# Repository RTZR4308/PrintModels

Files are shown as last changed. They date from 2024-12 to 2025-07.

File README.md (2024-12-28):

# База 3D моделей РТЗР

### Структура репозиторію
`Виробник/Пристрій/Модель/виробник_пристрій_назва_моделі.stl`  
  
_Наприклад:_  
`DJI/RM510B/Ntype/dji_rm510b_4Ntype_mount_hdmi.stl`  
> Виробник та пристрій дублюються в назві файлу, щоб при його використанні поза межами репозиторію було простіше орієнтуватись в його призначенні. 

Кожна модель або категорія моделей має свій README з описом файлів, параметрами друку та виглядом моделі.

## Правила використання репозиторію
1. Притримуйтесь структури репозиторію.
2. Створюйте теги при додаванні нових версій моделей.
3. Застарівші моделі не видаляються, а переносяться в папку deprecated там же, де й були.
4. Додавайте файли формату `.stl` або `.3mf` + `.stl`.
5. Оновлюйте README при внесенні змін.

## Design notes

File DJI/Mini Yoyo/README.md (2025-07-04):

# Документація по MINI YOYO
> Дисклеймер!
> 
> Оригінальна ідея та реалізація Йойо належить "Майстерні Незламності" 24 ОМБр. Нашим завданням було реалізувати цю ідею для DJI Matrice 4T. В ході розробки виявили, що отриманий результат можна використати не тільки для DJI Matrice 4T, а й адаптувати для 3 серії DJI Mavic.
> 
> Всі матеріали, конструкція та ідея ***цієї версії*** Йойо належать "Майстерні Потужності" (робоча назва) ББС 12 бригади спеціального призначення НГУ "Азов".
>
> Автори: Кроп, Азот, Годзі.

## Елементи
1. Arduino Pro Mini 5V
2. Micro-Servo GH-S037 або аналог ідентичного розміру TK-S037
3. Фоторезистор
4. Резистор 10К
5. USB Type-C OTG 
6. USBASP програматор AVR (https://www.rcscomponents.kiev.ua/product/usbasp-prohramator-avr-v2-0-draiver-i-pz-na-saiti-rcscomponents-kiev-ua_46535.html)

## Прошивка
#### ПЕРЕД БУДЬ-ЯКИМИ МАНІПУЛЯЦІЯМИ З ПЛАТОЮ, ЇЇ ТРЕБА ПРОШИТИ.
> Код прошивки можна знайти в репозиторії.

### Як прошивати?
Arduino Pro Mini with Atmega328P 
https://www.instructables.com/Uploading-Sketch-to-Arduino-Pro-Mini-using-usbASP/

Arduino Pro Mini with Atmega328PB
https://www.youtube.com/watch?v=LvKr8gG_WNg

## Cхема пайки


## Реалізація кнопки відкривання/закривання важеля
Використовується оригінальна кнопки RESET на Arduino Pro Mini. Нам необхідно перерізати доріжки на платі, що відповідають за оригінальну функціональність кнопки. На фото позначено червоними стрілками.


### Результат
Перевірити Мультиметром на продзвонці.
Контакт, що ближчий до 7-8 контактів (нижній на фото) не дзвониться на GND.
Контакт, що ближчий до 11-12 контактів (верхній на фото) не дзвониться на RST.
signal-2025-07-03-205428_005
signal-2025-07-03-205428_004

Таким чином ми від'єднали кнопку від її оригінальної функції. Вона більше не діє як RESET.
Далі нам треба буде припаяти провід Від верхнього контакту (ближчий до 11-12 контактів) до A0, на який в нас припаяно фоторезистор та резистор. 

Також припаяти провід від нижнього контакту (ближчий до 7-8 контактів) до `VCC`. Ми можемо припаяти проводок напряму до VCC з іншої сторони плати. Або ж використати коротший шлях, припаявшись до дальньої сторони резистора біля контакта 6 (див. фото). Цей контакт іде напряму на VCC.


### Що ми цим зробили?
При натисканні кнопки, на контакт A0 будемо подано 5 вольт з VCC, що аналогічно сигналу з фоторезистора, коли на нього світить яскраве світло. По суті, ми імітуємо світіння ліхтариком на фоторезистор, тим самим відкриваючи важіль, що тримає саму йойошку.

## Фінальний вигляд плати
signal-2025-07-03-205428_006

### РОЗТАШУВАННЯ ФОТОРЕЗИСТОРА ЗАЛЕЖИТЬ ВІД МОДЕЛІ ДРОНА, НА ЯКИЙ ВСТАНОВЛЮЄТЬСЯ ЙОЙО. ДИВІТЬСЯ ВІДПОВІДНЕ КРІПЛЕНННЯ.
signal-2025-07-03-205428_007

# Покроковий процес збірки
signal-2025-07-03-205428_010
signal-2025-07-03-205428_011
signal-2025-07-03-205428_012
signal-2025-07-03-205428_013
signal-2025-07-03-205428_014
signal-2025-07-03-205428_015
signal-2025-07-03-205428_016
signal-2025-07-03-205428_017
signal-2025-07-03-205428_018
signal-2025-07-03-205428_019
signal-2025-07-03-205428_020
signal-2025-07-03-205428_022
signal-2025-07-03-205428_023
signal-2025-07-03-205428_024
signal-2025-07-03-205428_025
signal-2025-07-03-205428_026
signal-2025-07-03-205428_027
## ПЕРЕД ВСТАНОВЛЕННЯМ ВАЖЕЛЯ, НЕОБХІДНО ПІД'ЄДНАТИ ЙОЙО ДО ЖИВЛЕННЯ, АБИ СЕРВОПРИВІД ВСТАВ У ПОЧАТКОВЕ НУЛЬОВЕ ПОЛОЖЕННЯ.
signal-2025-07-03-205428_028
signal-2025-07-03-205428_029
## Гвинтик для важеля входить в комплект сервоприводу.
signal-2025-07-03-205428_030
signal-2025-07-03-205428_031
signal-2025-07-03-205428_032
signal-2025-07-03-205443
signal-2025-07-03-205443_002
signal-2025-07-03-205443_003
signal-2025-07-03-205443_004

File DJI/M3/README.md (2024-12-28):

# Моделі для DJI Mavic 3
### [IR Cover](IR%20Cover)  
  
Знімок екрана 2024-12-28 194825

### [Кріплення для спарки батарей](Dual%20Bat)  
  


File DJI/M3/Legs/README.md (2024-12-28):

# Деталі для ніг DJI Mavic 3
### :books: Опис файлів
- `dji_m3_back_leg_plate.stl` - прокладка для задньої ноги
- `dji_m3_leg_bl.stl` - подовження для задньої лівої ноги
- `dji_m3_leg_br.stl` - подовження для задньої правої ноги
- `dji_m3_leg_fl.stl` - подовження для передня лівої ноги
- `dji_m3_leg_fr.stl` - подовження для передня правої ноги

### :gear: Параметри друку
- **PETG**
- Заповнення **100%**

### :eyes: Вигляд та спосіб кріплення
#### Подовження для передньої лівої ноги


#### Подовження для задньої ноги


#### Прокладка для задньої ноги


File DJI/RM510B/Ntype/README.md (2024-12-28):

# Кріплення під Ntype перехідники для зовнішніх антен на контролер DJI RM510B
### :books: Опис файлів
- `dji_rm510b_2Ntype_mount.stl` - верхнє кріплення під 2 N-type перехідника
- `dji_rm510b_2Ntype_mount_hdmi.stl` - верхнє кріплення під 2 N-type перехідника з отвором під блок переноса HDMI та Type-C роз'ємів 
- `dji_rm510b_2Ntype_mount_hdmi_kit_a1m.3mf` - комплект для переробки пульта під 2 N-type з блоком HDMI та Type-C. Пресет для Bambu Lab A1 Mini
- `dji_rm510b_4Ntype_mount.STL` - верхнє кріплення під 4 N-type перехідника
- `dji_rm510b_4Ntype_mount_hdmi.STL` - верхнє кріплення під 4 N-type перехідника з отвором під блок переноса HDMI та Type-C роз'ємів 
- `dji_rm510b_bottom_holder.STL` - нижнє кріплення, що закриває оригінальні HDMI та Type-C роз'єми
- `dji_rm510b_cable_tunnel.STL` - тунель для кабелів-перехідників  HDMI та Type-C
- `dji_rm510b_hdmi_holder.STL` - блок переноса HDMI та Type-C роз'ємів
- `dji_rm510b_hdmi_holder_cover.STL` - кришка блок переноса HDMI та Type-C роз'ємів 
- `dji_rm510b_hdmi_holder_plug.STL` - заглушка для отвору під блок з роз'ємами

### :gear: Параметри друку
- **PETG**
- Заповнення **50%**

### :eyes: Вигляд та спосіб кріплення
#### Комплект під 2 N-type з переносом HDMI і Type-C роз'ємів наверх  

  
#### Варіант з переносом HDMI і Type-C роз'ємів наверх  

  
#### Варіант без HDMI і Type-C роз'ємів  


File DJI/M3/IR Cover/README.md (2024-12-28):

# Кришка для інфрачервоного датчика DJI Mavic 3
### :books: Опис файлів
- `dji_m3_IR_cover.stl` - оригінальна модель

### :gear: Параметри друку
- **PETG**
- Заповнення **85%**

### :eyes: Вигляд та спосіб кріплення
Знімок екрана 2024-12-28 194825

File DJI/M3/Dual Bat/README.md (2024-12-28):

# Кріплення для спарки батарей на DJI Mavic 3
### :books: Опис файлів
- `dji_m3_dual_bat.stl` - оригінальна модель
- `dji_m3_dual_bat_99scale_8parts_x1c.3mf` - пресет на 8 деталей для Bambu Lab X1 Carbon. **Модель зменшена до 99%.**
### :gear: Параметри друку
- PETG
- Заповнення 15-30%
- Масштаб 99% (в залежності від пластику та принтера)

### :eyes: Вигляд та спосіб кріплення
  
  
⚠️ **Виступи на внутрішній стороні деталі мають зайти в вентиляційні отвори на задній частині дрона**  


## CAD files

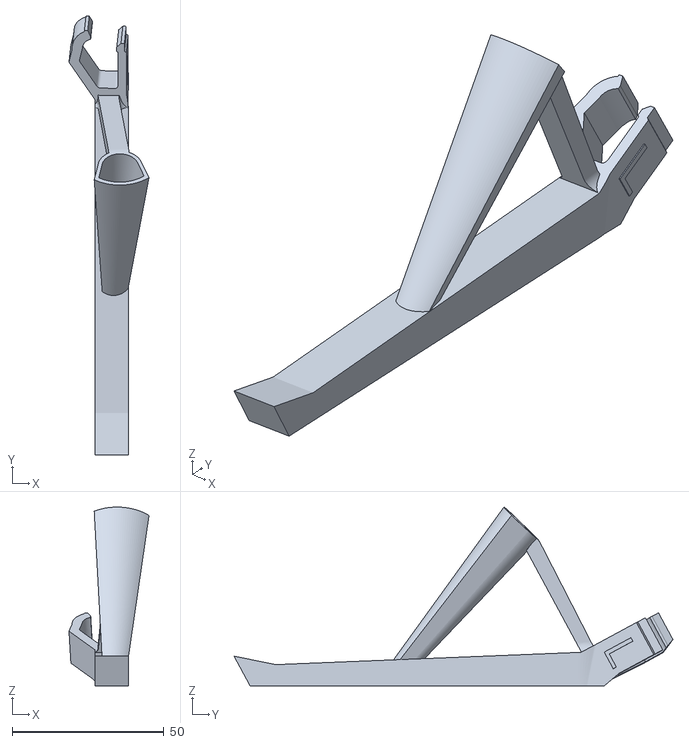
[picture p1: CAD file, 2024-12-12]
Autel/autel_4tmax_leg_lb.stl
26.4 x 144.6 x 58.9

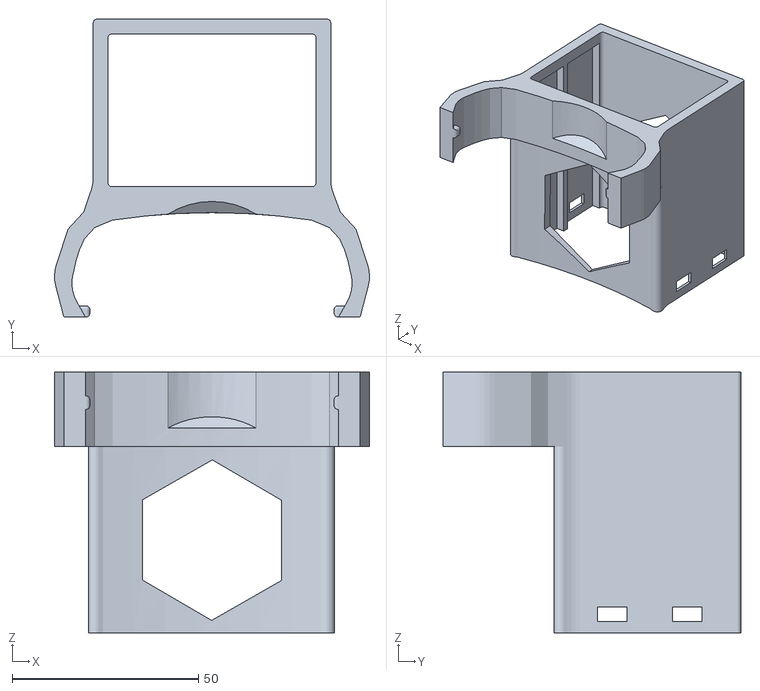
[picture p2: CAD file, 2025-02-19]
Autel/Dual Bat/autel_top_holder_V2.STL
84.6 x 80.0 x 70.0

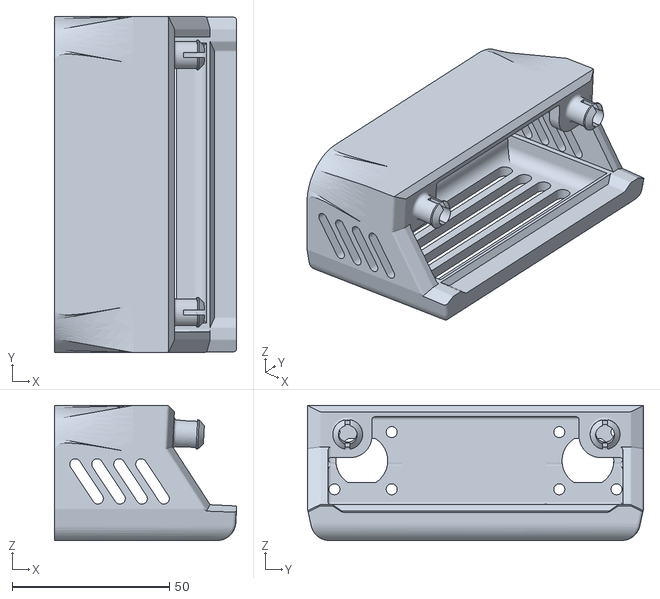
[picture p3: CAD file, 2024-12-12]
Controllers/2Ntype_4nut_Mount_air_.STL
58.1 x 107.0 x 43.0

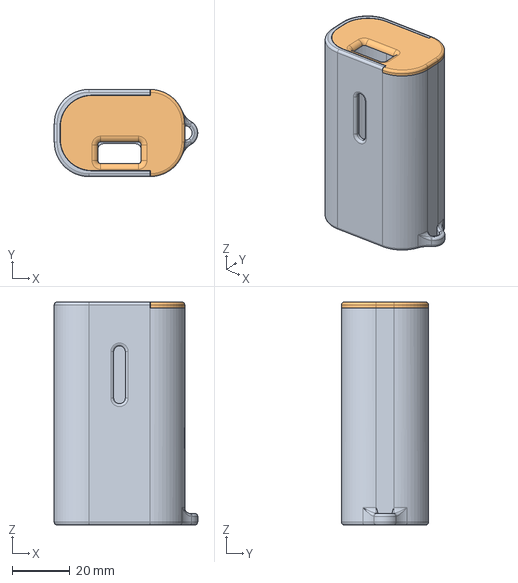
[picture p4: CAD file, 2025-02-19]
DJI/FPV/dji_fpv_googles_battery_case.step
49.7 x 30.2 x 77.2 mm

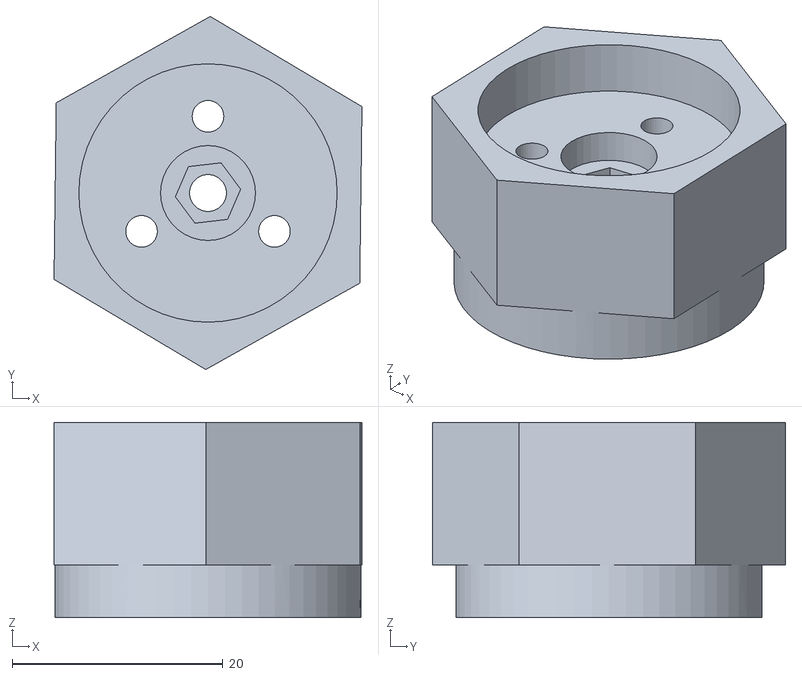
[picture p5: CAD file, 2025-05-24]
DJI/M3/dji_m3_motor_disasembler.STL
29.2 x 33.5 x 18.5

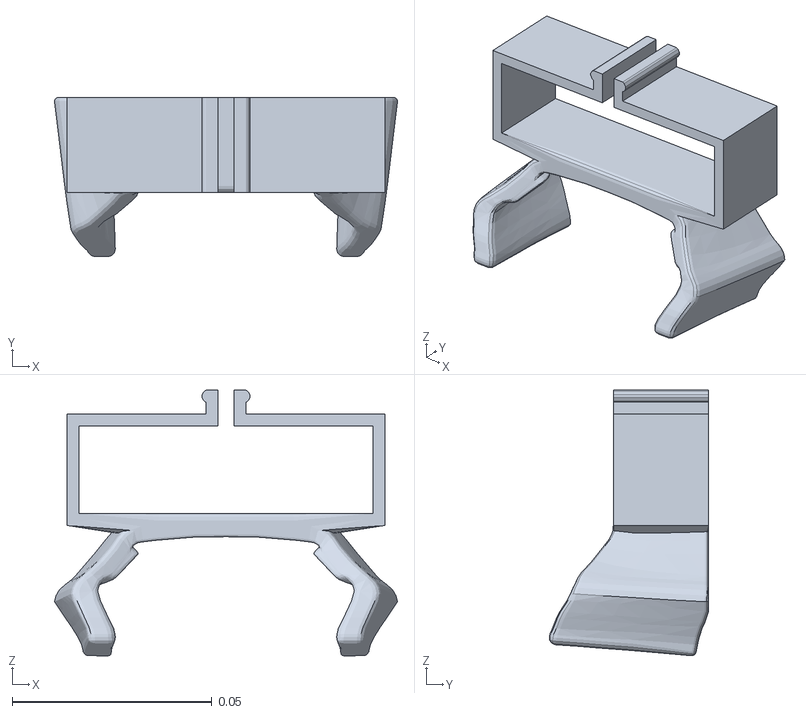
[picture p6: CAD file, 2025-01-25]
DJI/M3/Dual Bat/dji_m3_dual_bat_fpv.stl
0.0858 x 0.0398 x 0.0664

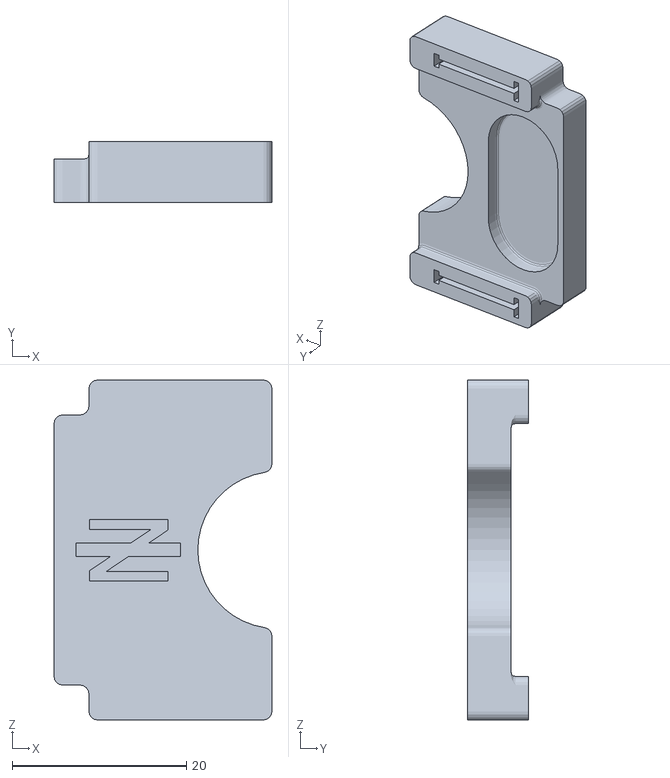
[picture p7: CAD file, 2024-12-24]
DJI/M3/IR Cover/dji_m3_IR_cover.stl
25.0 x 7.00 x 39.0

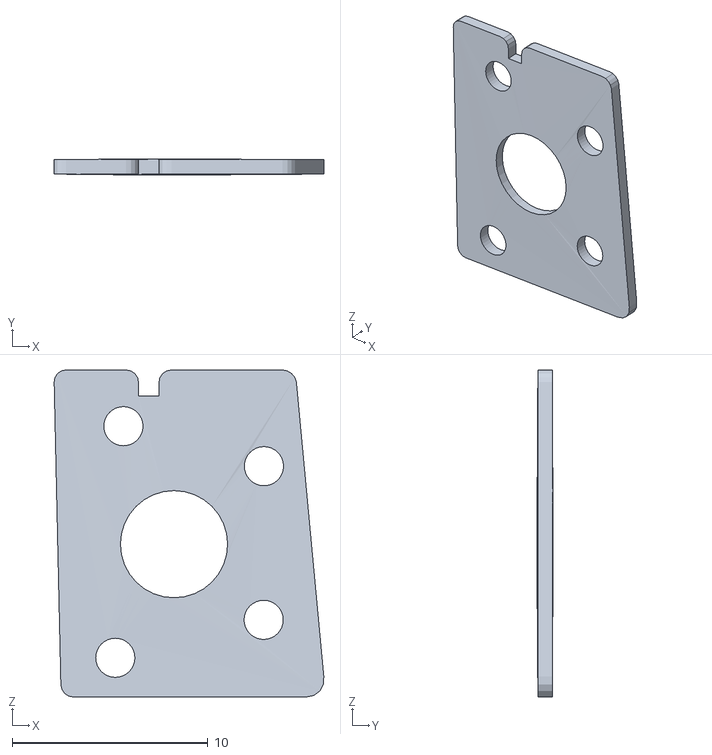
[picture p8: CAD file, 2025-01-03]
DJI/M3/Legs/dji_m3_back_leg_plate.stl
13.8 x 0.8 x 16.7

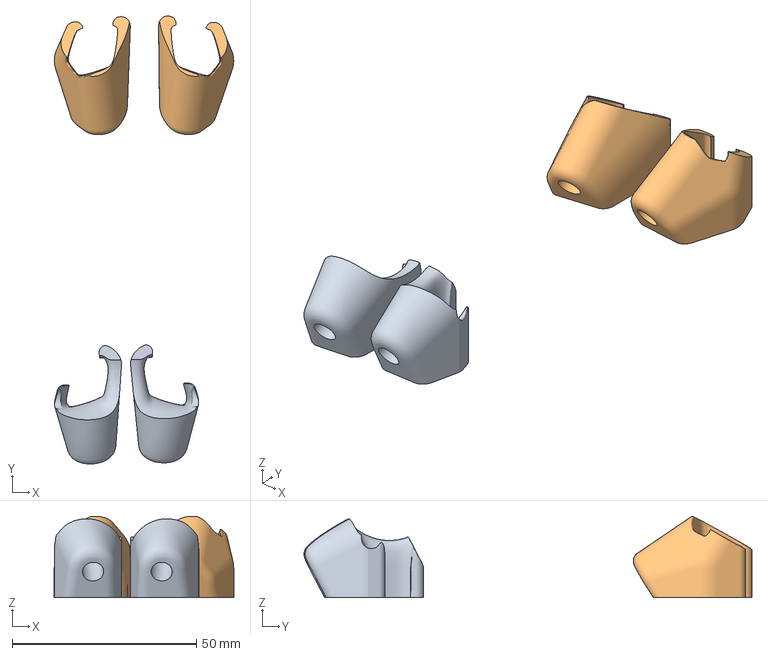
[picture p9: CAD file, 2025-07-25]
DJI/M4/dji_m4_arm_bracket_set.3mf
48.7 x 121.6 x 22.1 mm
Збірка x 2

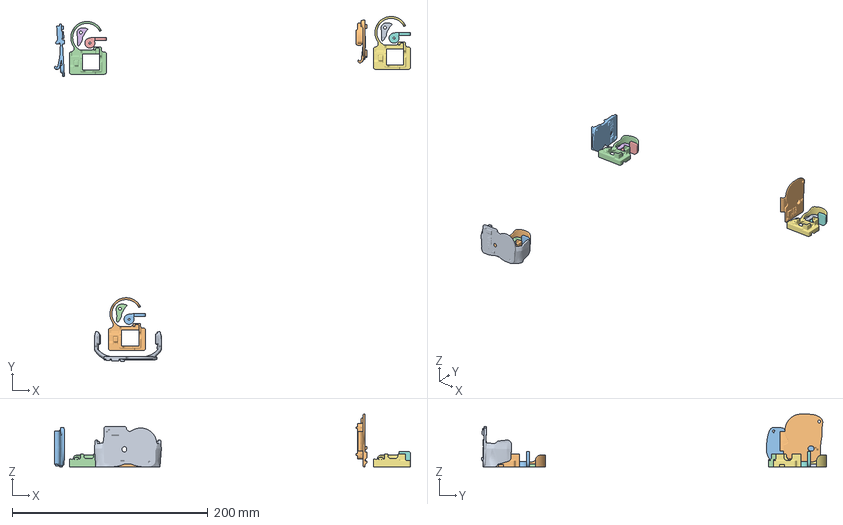
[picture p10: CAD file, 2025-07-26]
DJI/Mini Yoyo/dji_mini_yoyo_set.3mf
364.5 x 352.8 x 54.0 mm
dji_m4t_mini_yoyo_mount.stl
dji_m3_pro_mini_yoyo_mount.stl
dji_m3_mini_yoyo_mount.stl
mini_yoyo.stl_1 x 3
mini_yoyo.stl_2 x 3
mini_yoyo.stl_3 x 3

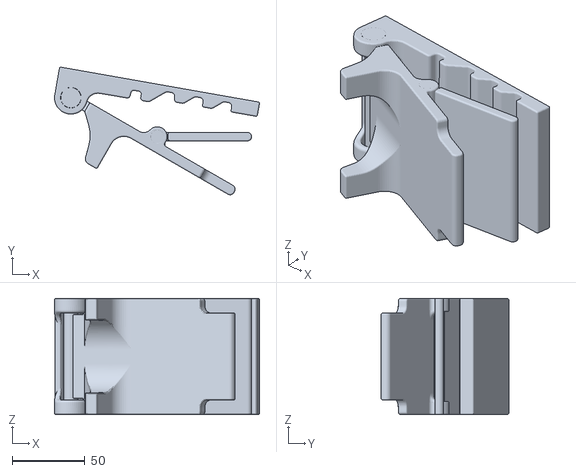
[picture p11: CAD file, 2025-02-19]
DJI/RM510B/Foldable DJI RC Pro Stand.stl
141.3 x 87.9 x 80.0

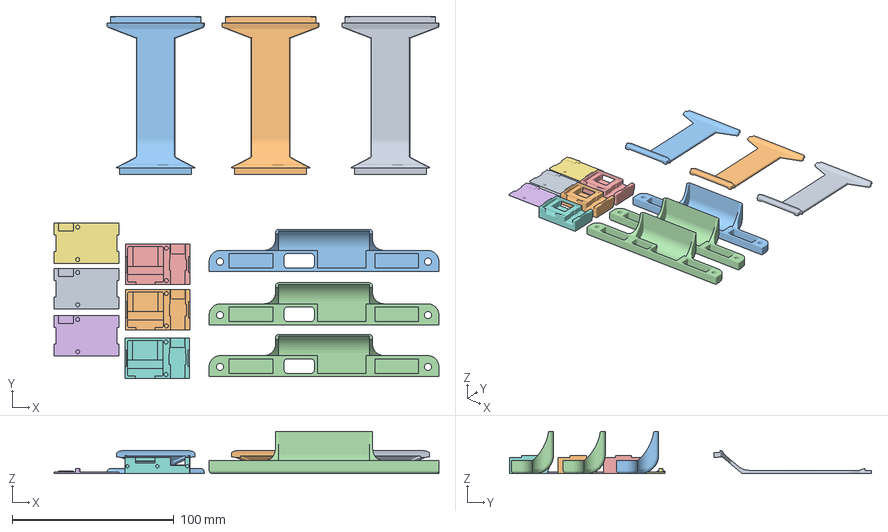
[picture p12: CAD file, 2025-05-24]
DJI/RM510B/Ntype/dji_rm510b_Ntype_mount_hdmi_3kit_ x1.3mf
237.8 x 223.7 x 26.0 mm
cable_tunnel.STL x 3
bottom_holder.STL x 3
hdmi_holder.STL x 3
hdmi_holder_cover.STL x 3

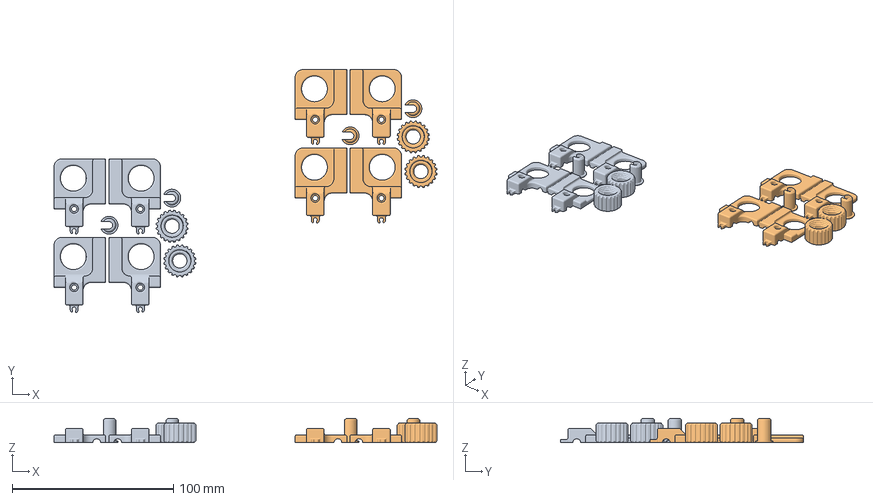
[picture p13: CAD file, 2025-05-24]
DJI/RM700B/dji_rm700b_N_type_holder_x2_separate_print.3mf
237.3 x 150.5 x 15.0 mm
Складання x 2

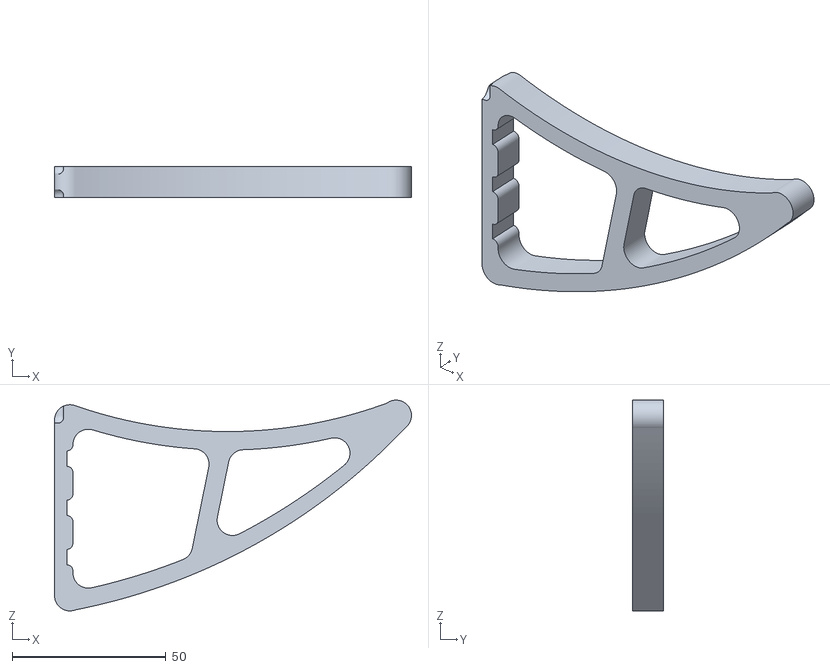
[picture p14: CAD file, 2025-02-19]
FPV/FPV7_long_legs.stl
116.0 x 10.0 x 68.5

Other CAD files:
Other/Tube_fixator.stl
Starlink/Reductor Starlink.step
Autel/autel_4tmax_leg_rf.stl
Autel/Dual Bat/autel_top_holder_front_V2.STL
Autel/autel_4tmax_leg_lf.stl
Autel/autel_4tmax_leg_rb.stl
Controllers/2Ntype_Mount_air_.STL
Controllers/2Ntype_Mount_air_wings.STL
Controllers/rm510_4Ntype_Mount_air.STL
DJI/M3/Dual Bat/dji_m3_dual_bat.stl
DJI/M3/Dual Bat/dji_m3_dual_bat_99scale_8parts_x1c.3mf
DJI/M3/Dual Bat/dji_m3_dual_bat_fpv_99scale_8parts_x1c.3mf
DJI/M3/Legs/dji_m3_leg_bl.stl
DJI/M3/Legs/dji_m3_leg_br.stl
DJI/M3/Legs/dji_m3_leg_fl.stl
DJI/M3/Legs/dji_m3_leg_fr.stl
DJI/M4/dji_m4_arm_bracket.stl
DJI/M4/dji_m4_double_bat.step
DJI/Mini Yoyo/dji_m3_mini_yoyo_mount.stl
DJI/Mini Yoyo/dji_m3_pro_mini_yoyo_mount.stl
DJI/Mini Yoyo/dji_m4t_mini_yoyo_mount.stl
DJI/Mini Yoyo/mini_yoyo.stl
DJI/Mini Yoyo/yoyo_cartridge.stl
DJI/Mini Yoyo/yoyo_cartridge_24_set.3mf
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

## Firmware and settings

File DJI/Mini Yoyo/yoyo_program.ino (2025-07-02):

#include "ServoSmooth.h"

ServoSmooth servo;

uint32_t myTimer;
int SensorPin = A0;  // analog pin used to connect the potentiometer
int val;             // variable to read the value from the analog

void setup() {

  servo.attach(2);  // Digital pin for servo signals
  servo.setSpeed(410);   // speed limit
  servo.setAccel(0.95);  // acceleration
  pinMode(13, OUTPUT); // standard command, let it be
}
void loop() {
  // set desired servo position using setTargetDeg(angle) or setTarget(impuls length)
  // when tick() is invoked, move servo with set speed and acceleration
  boolean state = servo.tick();  // servo movement according to internal timer!
  if (millis() - myTimer >= 20) {
    myTimer = millis();
    val = analogRead(SensorPin);  // reads the value of the potentiometer (value between 0 and 1023)
    if (val >= 900) {
      servo.setTargetDeg(0);
    } else {
      servo.setTargetDeg(90);
    }
  }
}

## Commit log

2024-12-12 Models from Google Drive
    [2Ntype_4nut_Mount_air_.STL, 2Ntype_Mount_air_.STL, 2Ntype_Mount_air_wings.STL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]
2024-12-17 Updated version of Ntype Mount with HDMI holder
    [2Ntype_Mount_air_wings_0.1_.STL, 4Ntype_Mount_air_HDMI_wings_.STL, 4Ntype_Mount_air_wings_0.1_.STL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]
2024-12-18 Reworked repository structure.
    [2Ntype_Mount_air_.STL, 2Ntype_Mount_air_wings.STL, SMA_NUT-twister.STL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]
2024-12-24 PETG (coPET), 85% infill.
    [dji_m3_IR_cover_85_INFILL_PETG.stl]
2024-12-28 Moved dji m3 dual bat file to a separate folder.
    [dji_m3_dual_bat.stl]
2024-12-28 Added 3mf for 8 dual bat holders with 99% scale for X1 printer.
    [dji_m3_dual_bat_99scale_8parts_x1c.3mf]
2024-12-28 Moved M3 models to separate folders.
    [dji_m3_IR_cover_85_INFILL_PETG.stl, dji_m3_leg_br.stl, dji_m3_leg_fl.stl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]
2024-12-28 Moved RM510b Ntype models to a separate folder.
    [2Ntype_Mount_air_.STL, 2Ntype_Mount_air_wings.STL, dji_rm510b_2Ntype_4nut_Mount_air_.STL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]
2024-12-28 Added 2Ntype mount with HDMI.
    [dji_rm510b_2Ntype_mount_hdmi.stl]
2024-12-28 Added 2Ntype mount with hdmi kit preset for A1 mini.
    [dji_rm510b_2Ntype_mount_hdmi_kit_a1m.3mf]
2024-12-28 PETG, 85% infill
    [dji_m3_IR_cover.stl]
2025-01-03 Version with correst thickness.
    [dji_m3_back_leg_plate.stl]
2025-01-25 Added Starlink leg cap model
    [dji_m3_dual_bat_fpv.stl, dji_m3_dual_bat_fpv_99scale_8parts_x1c.3mf, starlink_leg_cap.stl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]
2025-01-25 Added work in progress projects step files. You can use it while I'm out.
    [Dzyga.3mf, Dzyga.step, Reductor Starlink.step]
2025-02-19 New models
    [Alientech_double_mount.STL, DJI FPV Googles Battery Case.step, Dzyga.3mf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]
2025-03-28 Updated Ntype mount with different logos and Ntype plug.
    [dji_rm510b_4Ntype_mount_hdmi_IN.step, dji_rm510b_4Ntype_mount_hdmi_RTZR.step, dji_rm510b_Ntype_plug.step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]
2025-03-28 Updated finished projects.
    [DJI FPV Googles Battery Case.step, Dzyga.step, Reductor Starlink.step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]
2025-05-24 New and updated models
    [Dzyga.3mf, Reductor ST-box v17.3mf, dji_m3_motor_disasembler.STL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]
2025-07-02 Added Mini Yoyo
    [dji_m3_mini_yoyo_mount.stl, dji_m3_pro_mini_yoyo_mount.stl, dji_m4t_mini_yoyo_mount.stl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]
2025-07-05 Added yoyo cartridge
    [yoyo_cartridge.stl, yoyo_cartridge_24_set.3mf]
2025-07-05 Updated component orientation.
    [dji_m3_mini_yoyo_mount.stl, dji_m3_pro_mini_yoyo_mount.stl, dji_m4t_mini_yoyo_mount.stl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]
2025-07-25 Added drone type text to yoyo mounts.
    [dji_m3_mini_yoyo_mount.stl, dji_m3_pro_mini_yoyo_mount.stl, dji_m4_double_bat.step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]
2025-07-25 Tube fixator for Una
    [Tube_fixator.stl, Tube_holder.stl]
2025-07-25 Set of arm brackets for 1 Matrice 4.
    [dji_m4_arm_bracket_set.3mf]
2025-07-26 Made rope holder hole smaller.
    [dji_m3_pro_mini_yoyo_mount.stl, dji_mini_yoyo_set.3mf]
